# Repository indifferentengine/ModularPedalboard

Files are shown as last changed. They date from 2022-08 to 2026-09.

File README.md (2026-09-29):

# The Indifferent Engine Modular Pedalboard
A modular pedalboard system for guitars, bass and vocal effect rigs. 

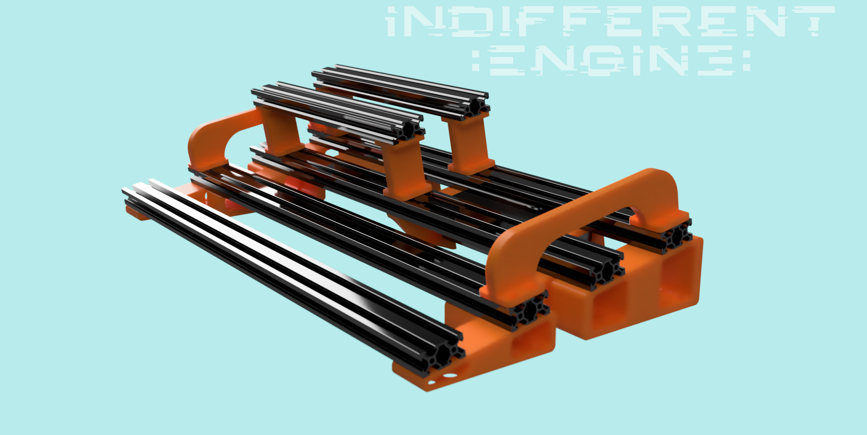
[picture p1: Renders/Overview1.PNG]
4x600mm board render


Constructed from 3D printed parts, off-the-shelf 2040 aluminium extrusion and velcro.

Simply print out the modular parts for the size and complexity of board you want and bolt them onto some aluminium extrusion.

# Designer App

We've launched a [designer app](https://www.indifferentengine.com/pedalboard) that you can use to mock up your pedalboard design. You can then either purchase the board as a self-assembly kit, or use the summary page to download the STLs for home printing.

# Where to find extrusions

Aluminium extrusions are standardised in width and profile, and are easy to find world-wide.

For this project, you need "2040 Aluminium Extrusion".

Extrusions can be found from many suppliers - often suppliers will cut the extrusions to length for you, simply google "2040 aluminium extrusion cut to length" to locate a supplier. Use the length of extrusion that matches the board width you want. For reference, Adam Paul's prototype board (shown in pictures at the bottom of this page) uses a set of four 600mm aluminium 2040 extrusion.

Here's the supplier we use (UK based):
[Ooznest](https://ooznest.co.uk/product/v-slot-linear-rail-20x40mm-cut-to-size/)

# Non-slip feet

The latest V2 release includes indentations for non-slip rubber feet. The feet we use are [3M™ Bumpon™ SJ 5007 Black Polyurethane Rubber Foot 10.2mm x 2.5mm](https://www.rapidonline.com/3m-bumpon-sj-5007-black-polyurethane-rubber-foot-10-2mm-x-2-5mm-single-49-4704)

# Different options

The components are designed to allow the user to build up a board of many different sizes and options.

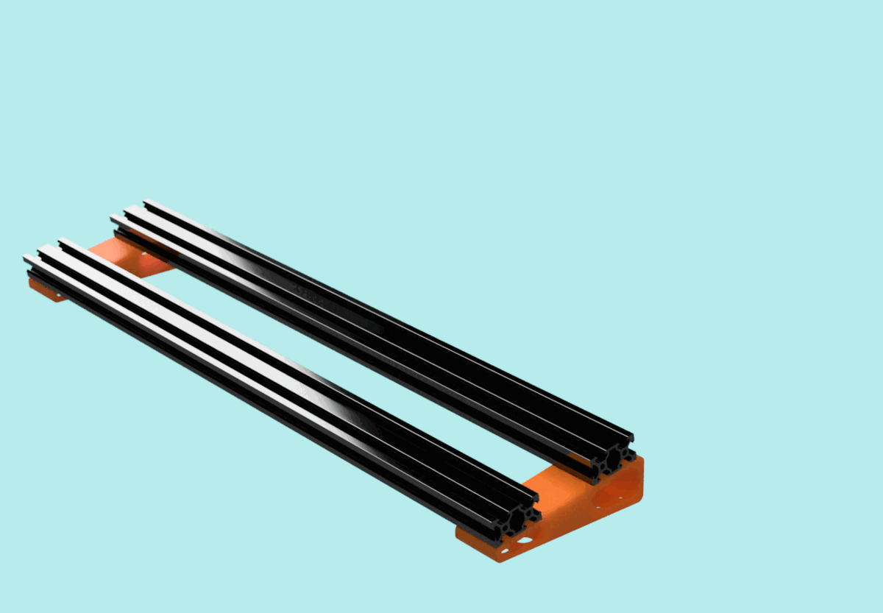
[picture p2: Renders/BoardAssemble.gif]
different board options gif


You can make boards of many sizes with this modular system. You can use 2, 3 or 4 rails and the length of the rails can be cut to whatever width of board you are after.

You could go as small as a 2 rail, 300mm wide board, like this:

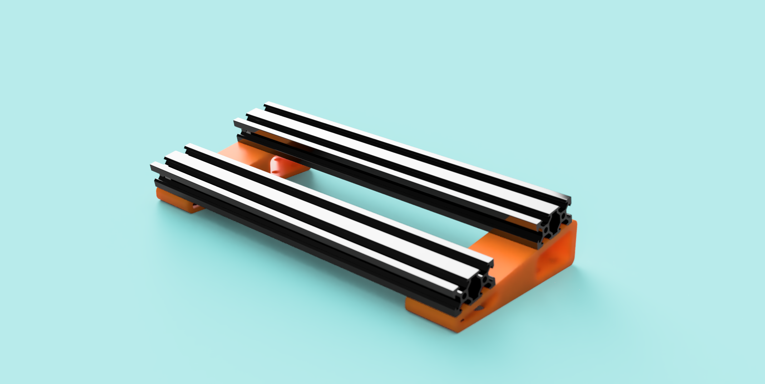
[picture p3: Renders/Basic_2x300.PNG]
basic 2x300mm board


Or as big as a 4 rail, 600mm wide board, like this:

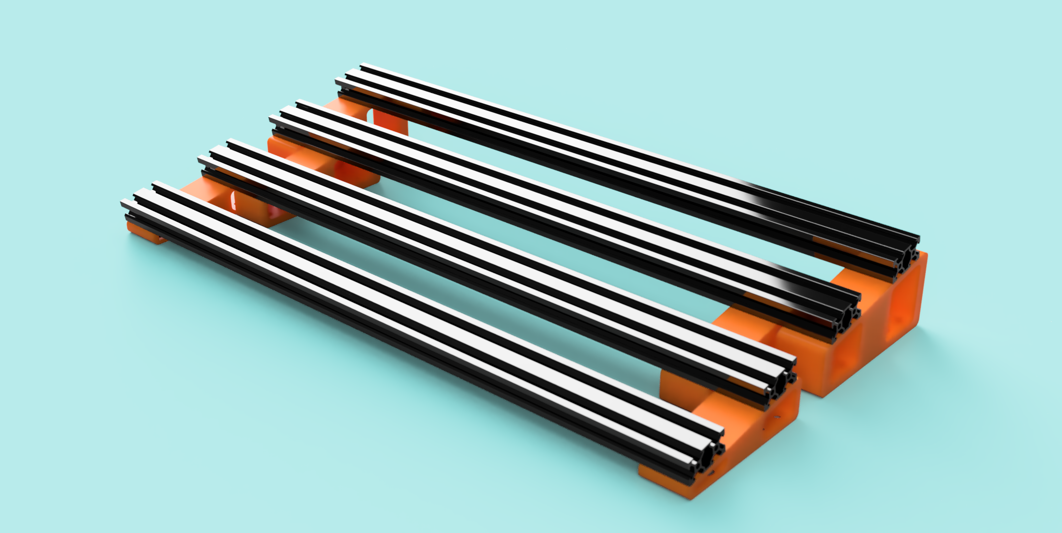
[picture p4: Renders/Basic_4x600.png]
basic 2x300mm board


You can even go wider than 600mm if you wanted to, especially if you add extra braces for the center of the board.

There are also a few extra options, I've included:
* A 4 in, 4 out patch bay that can be mounted either underneath or on-top of the board (on-top only for boards smaller than 4 rails). Designed to fit standard 1/4" open style jacks.
* A 2-piece handle that can be printed to go either end of the board (minimum 3 rail boards and up).
* A 2-piece tier support, which can be printed to allow the attachment of extra rails above the main board. These are designed to allow for boss-sized pedals to fit underneath the upper tier.
* An under-board powersupply mount for a T-Rex Chameleon (this is the power supply I have on hand). For 4-rail boards only.

The intention is to continue to support the project and further add to the range of modular parts to allow people to design a huge range of board setups.

# 3D Printing

We print these parts in PLA at 60% infill with 0.32 layer height. All parts print without supports.

# How To Build

Decide how many rails you want on your main board; 2, 3 or 4. You will need to print the following braces:

| Rails  | Braces required |
| ---| --- |
| 2 | 2x Brace1 |
| 3 | 2x Brace1, 2x Brace2 |
| 4 | 2x Brace1, 2x Brace2, 2xBrace3 |

Once completed, bolt your braces to the ends of the aluminium extrusion using 10mm M5 bolts and M5 T-slot nuts. Each brace requires 8 nuts and bolts. We recommend glueing some large rubber feet to the bottom of the braces to prevent the board from slipping around on stage.

If you want to add an upper tier you can use tier supports. Tier supports come in two pieces which sandwich together. So for a single upper rail, you will need 4x tier supports. Bolt the supports to both the upper and lower rails using 4x M5 bolts and T-slot nuts.

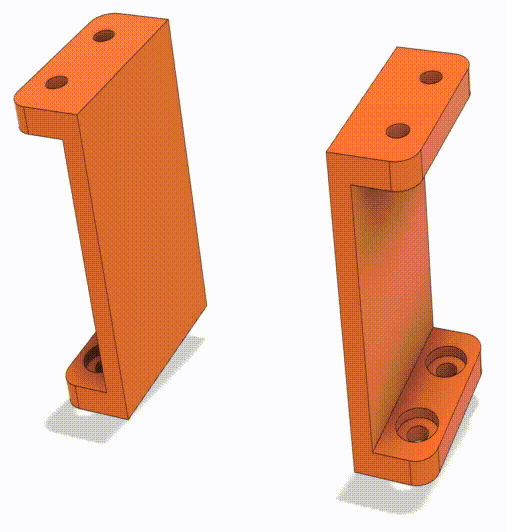
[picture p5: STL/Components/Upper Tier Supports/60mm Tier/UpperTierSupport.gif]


The patch bay requires 4x M5 bolts and T-slot nuts. The patchbay can be mounted to the top side of the board, or underneath the board in the case that you are building a 4-rail board. 

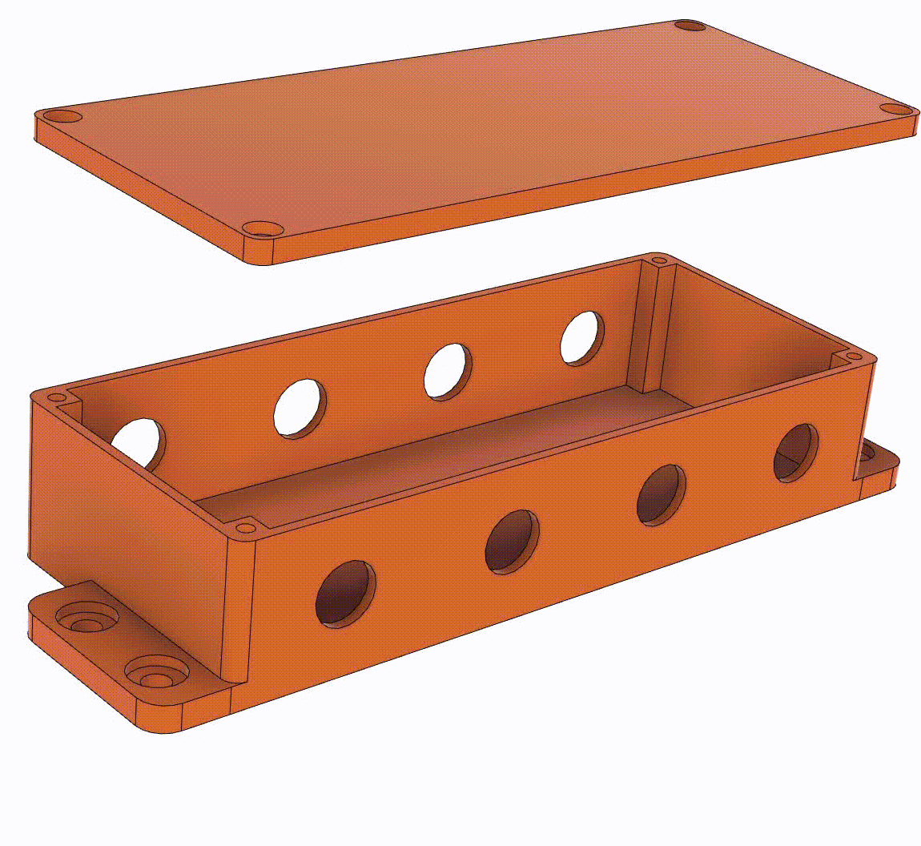
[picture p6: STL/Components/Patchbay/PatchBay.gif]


The powersupply mounting for T-rex Chameleon requires 8x M5 bolts and T-slot nuts, and only fits 4-rail boards. It must mount on the back 2 rails.

Handles are printed in 2 parts for each handle, in a similar way to the upper-tier support. Print both sides of the handle, then sandwich them together and bolt to the top side of the board. The handles require 8x M5 bolts and T-slot nuts. These handles can only be used on 3 and 4 rail boards.

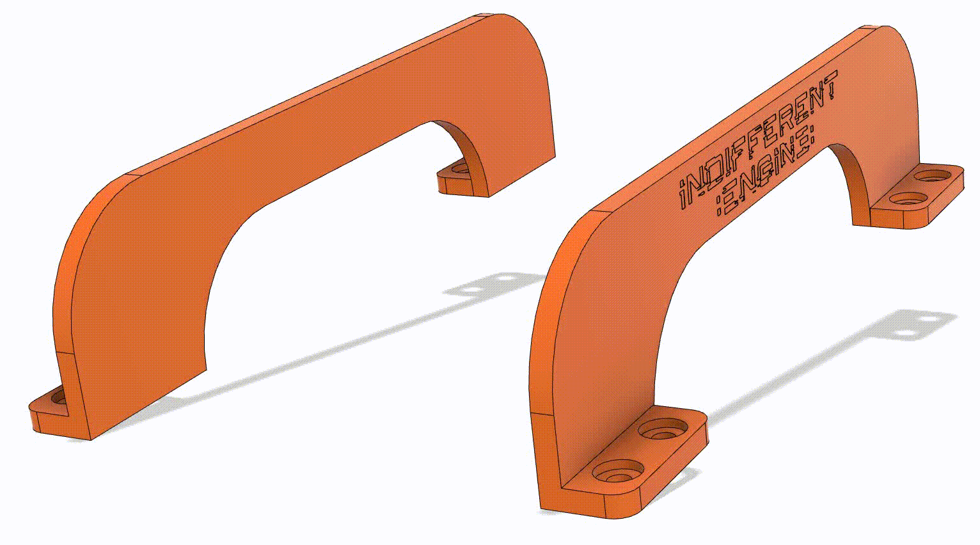
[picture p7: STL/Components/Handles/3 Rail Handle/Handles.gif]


Once the rails and other components are all mounted in place, simply cut some 40mm wide heavy-duty velcro carpet to length and stick it to the top of each rail. You're now ready to mount some pedals! Power and audio cabling can be run underneath the rails to keep it tidy, and you can use ziplocks to attach the cabling to the rails to keep it from trailing around under the board.

The following gif shows how a board with 4 rails, handles and an upper tier go together:



# Support the project

We may offer pedalboard kits in the future, keep an eye on our social stuff:
https://www.instagram.com/indifferentengine
https://www.facebook.com/indifferentengine

You can also help us out by checking out our merch store over here:
https://www.indifferentengine.com

If you want other ways to support us, considering buying one of our T-shirts, listening to our music or come to a show. Or just reach out for a chat.

# License

Licensed under GNU GPL v3. This means you are free to take this design and make any changes you like and then share those changes freely, so long as you make the source for your changes publicly available. This benefits everyone - because if you make some improvement, we can all benefit from it.

However, you cannot distribute compiled versions. In this context (a hardware device with CAD design), this effectively means you

a) cannot sell any physically manufactured item of any kind - either as parts or assembled.

b) cannot charge money for access to any source or CAD files that you choose to distribute

If you break these simple rules we will force you to be front row at one of our floor shows, where we can full-throat scream right in your sad little face.

If you would like a license to sell kits, contact us.

Everything is copyright (c) 2022 Indifferent Engine Ltd. Everything. OK? Indifferent Engine and the Indifferent Engine glitch logo are trademarks of Indifferent Engine Ltd.

# Photos
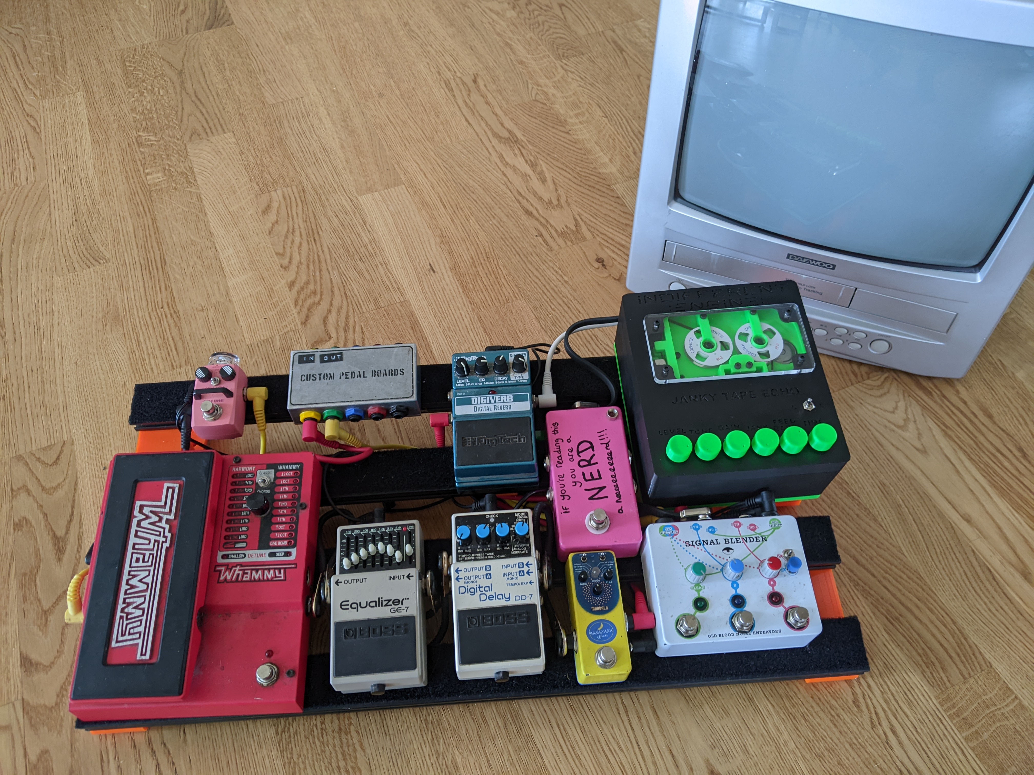
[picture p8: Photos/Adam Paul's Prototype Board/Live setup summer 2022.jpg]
Adams Board Top summer 2022

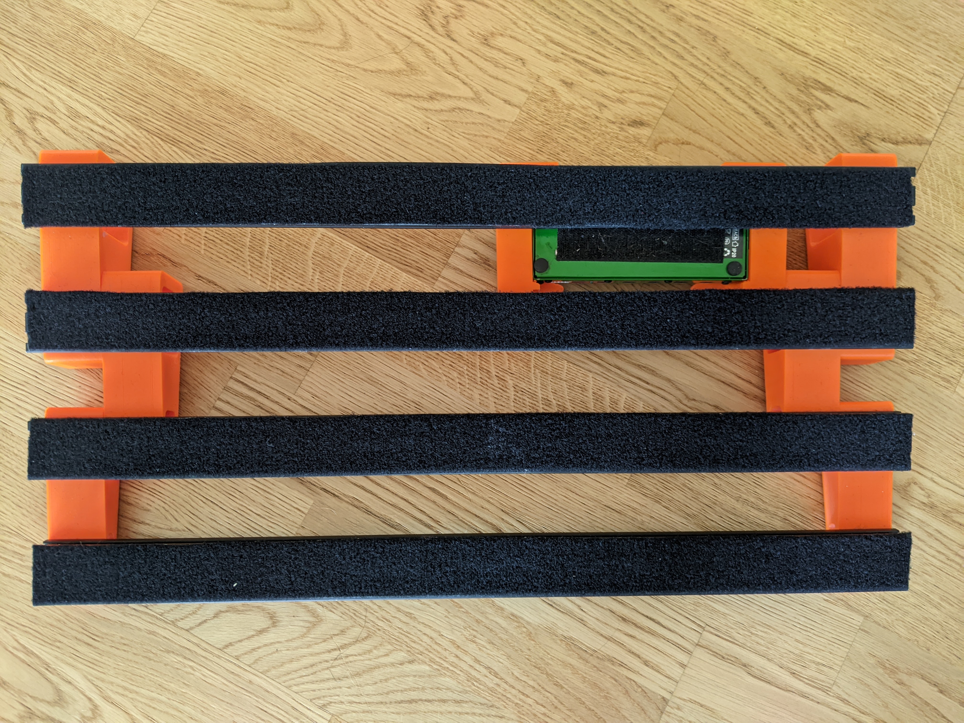
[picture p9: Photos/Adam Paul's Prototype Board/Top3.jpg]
Adams Board Top

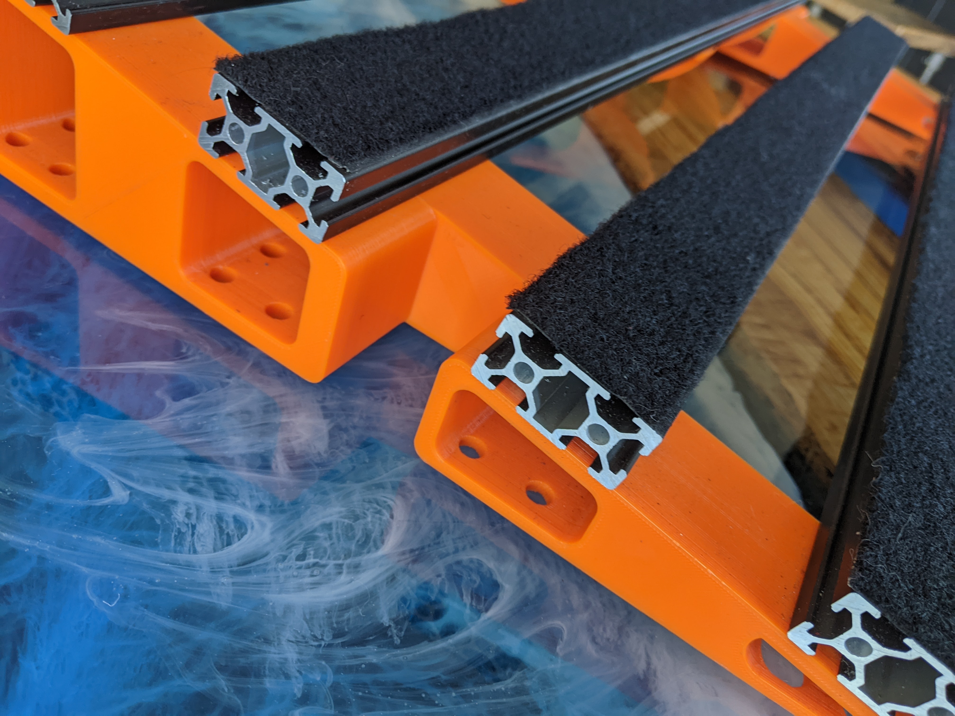
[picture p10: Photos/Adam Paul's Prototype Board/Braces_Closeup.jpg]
Adams Board Braces Closeup

Adams Board Rubber Feet
Adams Board TRex Chameleon mounting
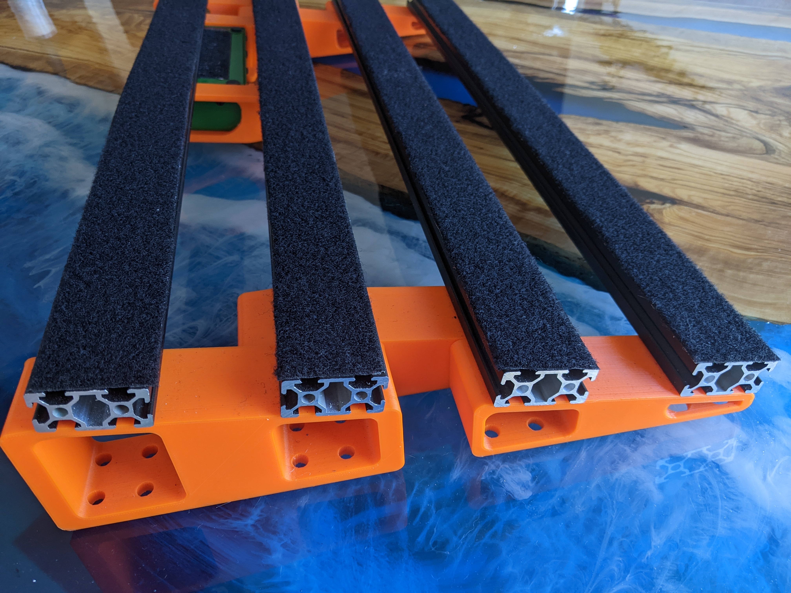
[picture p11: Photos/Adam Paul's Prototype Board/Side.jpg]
Adams Board Side


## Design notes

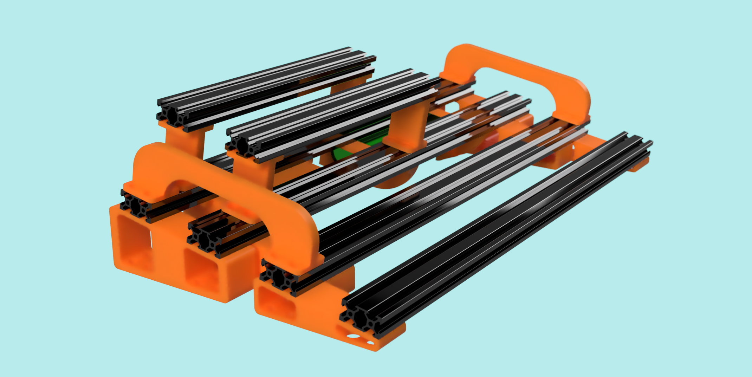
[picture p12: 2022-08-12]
Renders/Overview2.png

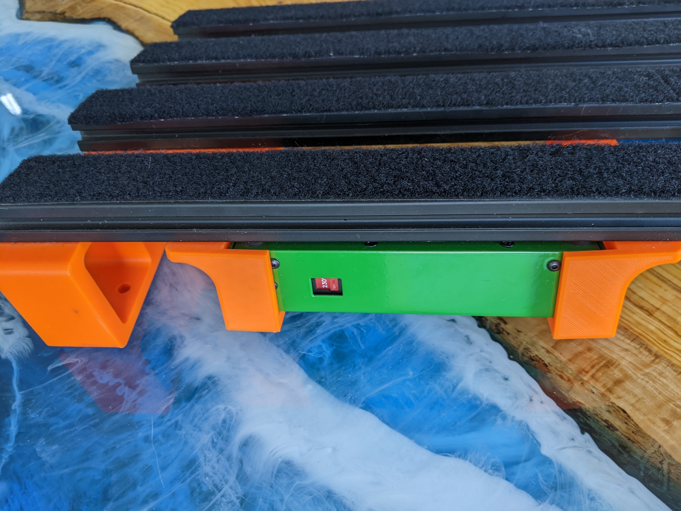
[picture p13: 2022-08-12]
Photos/Adam Paul's Prototype Board/TRexPowersupply_Back.jpg

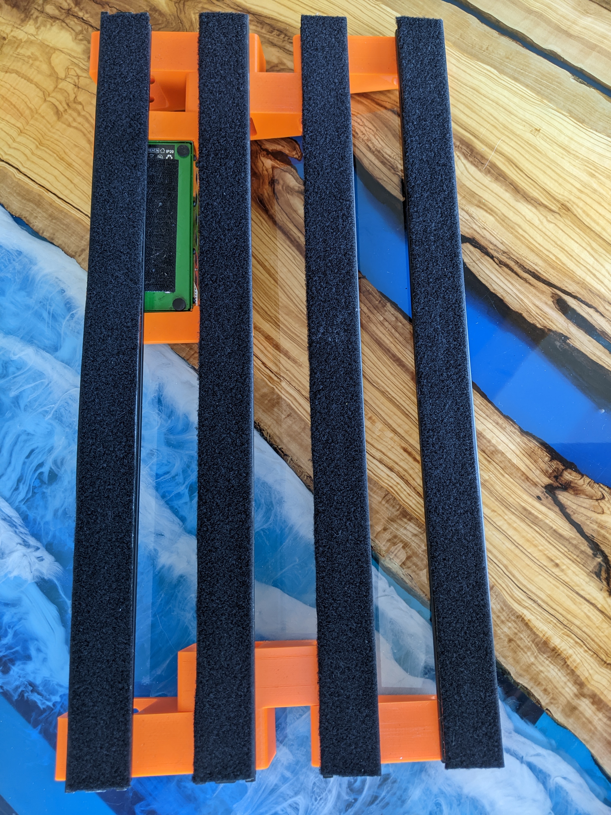
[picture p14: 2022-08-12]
Photos/Adam Paul's Prototype Board/Top2.jpg

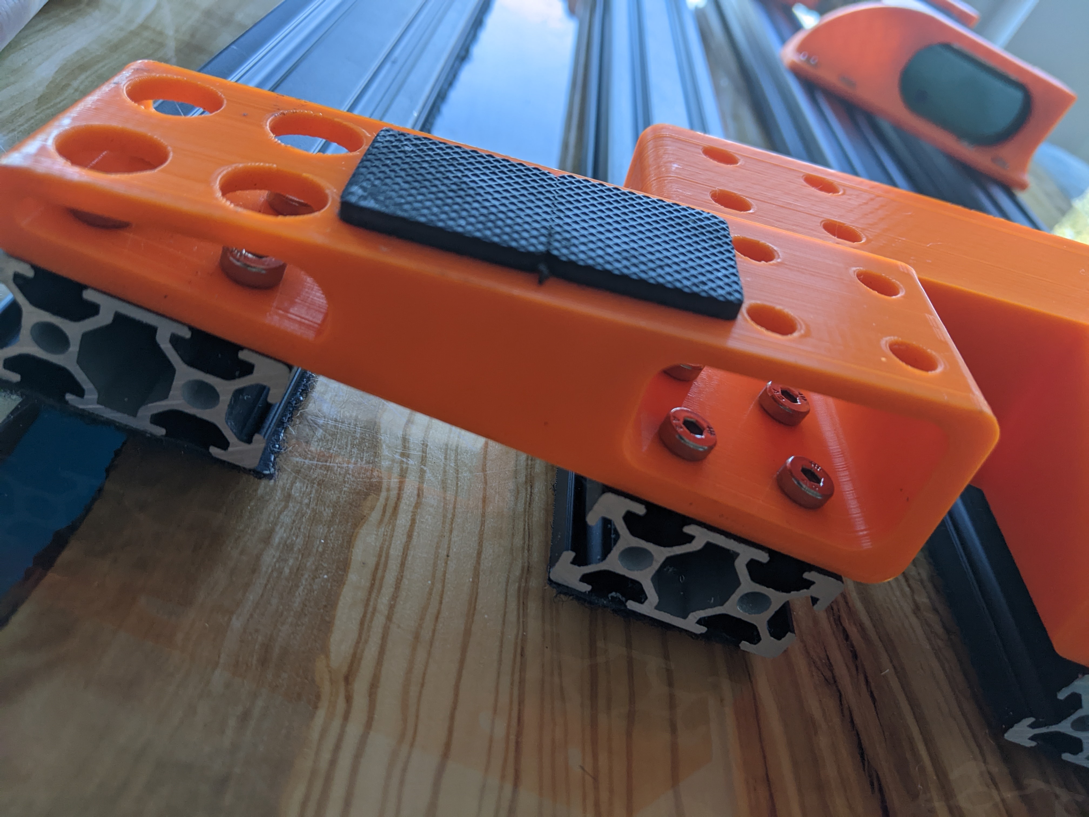
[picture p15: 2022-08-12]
Photos/Adam Paul's Prototype Board/RubberFeet1.jpg

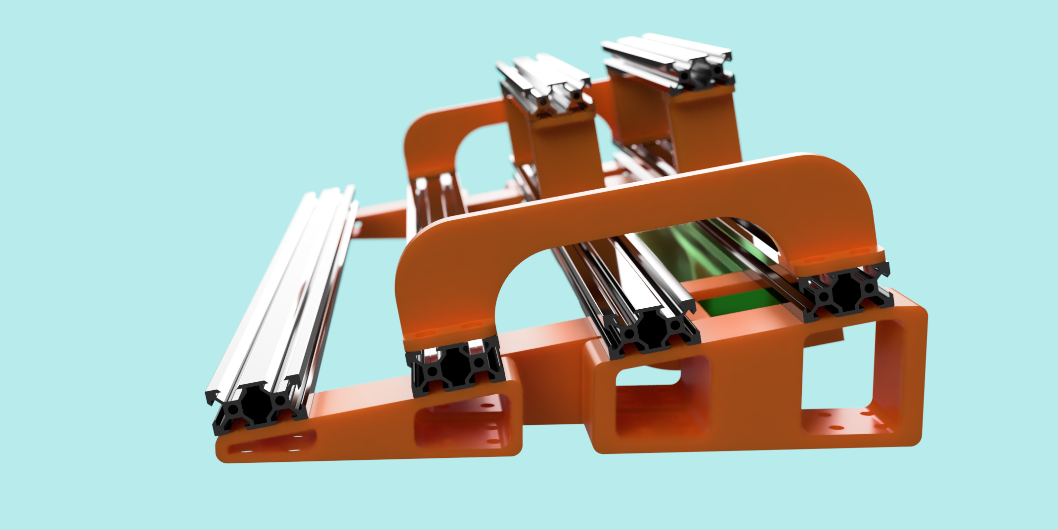
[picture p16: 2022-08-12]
Renders/side2.png

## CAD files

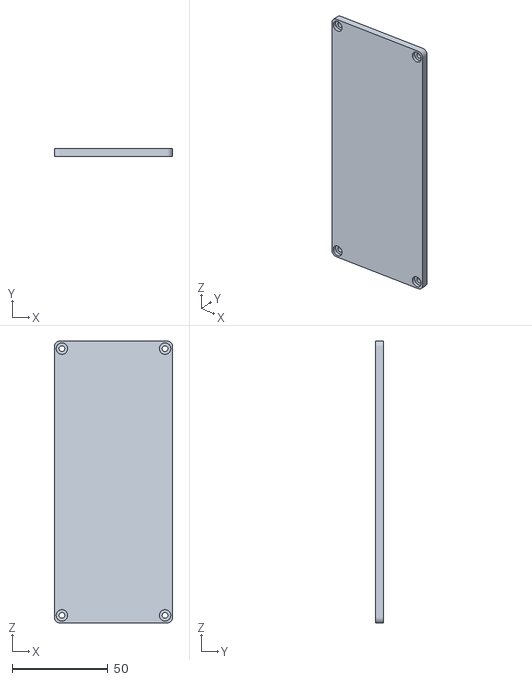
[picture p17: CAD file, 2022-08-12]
STL/Components/Patchbay/PatchBayLid.stl
62.0 x 4.00 x 147.6

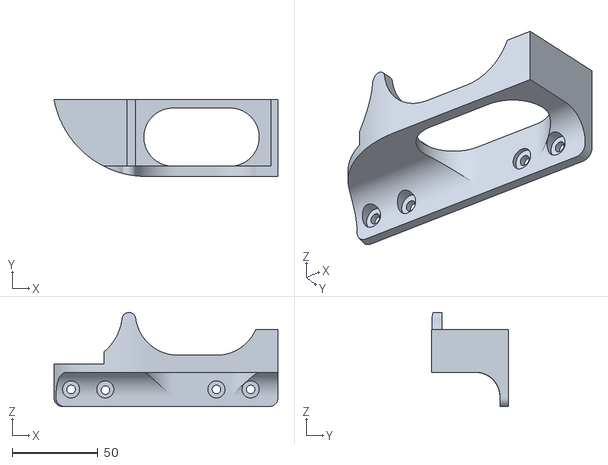
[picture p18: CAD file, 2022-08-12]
STL/Components/Power Supply Mounts/T-Rex Chameleon/PSUMount2.stl
131.0 x 45.0 x 55.0

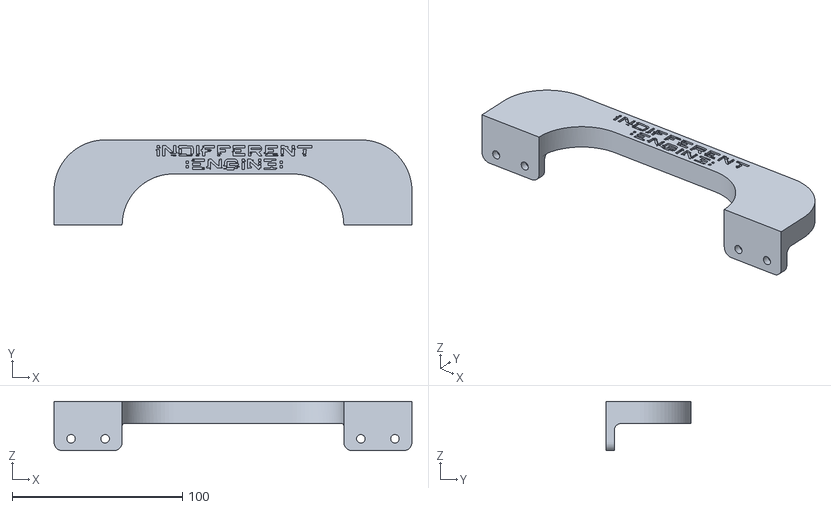
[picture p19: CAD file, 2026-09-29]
STL/part-handle1.stl
210.0 x 50.0 x 29.0

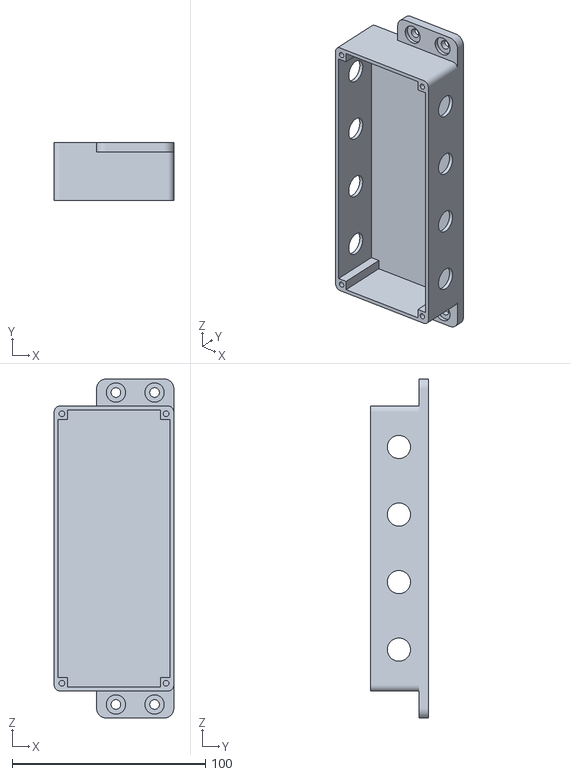
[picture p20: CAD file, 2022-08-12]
STL/Components/Patchbay/Patchbay.stl
62.0 x 30.0 x 175.6

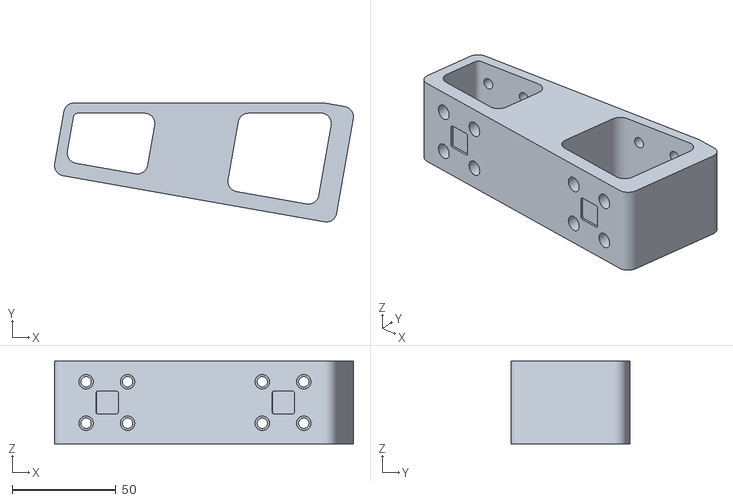
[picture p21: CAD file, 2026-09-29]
STL/part-brace-A2.stl
144.2 x 57.4 x 40.0

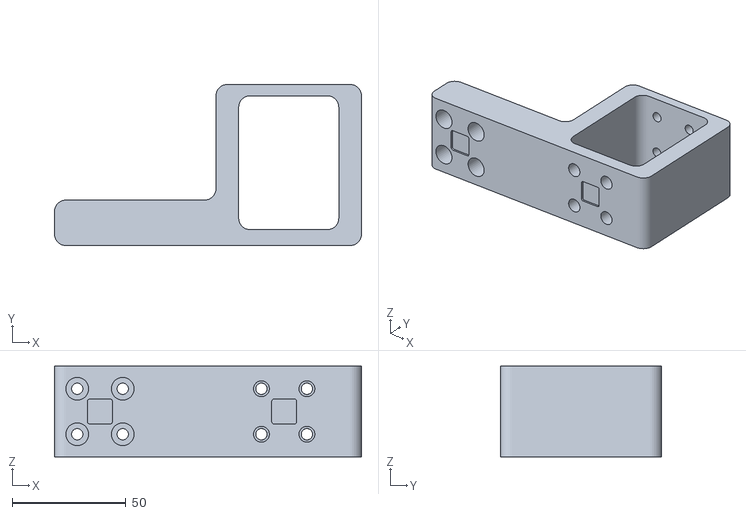
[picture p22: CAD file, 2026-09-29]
STL/part-brace-F1toF4.stl
135.0 x 70.9 x 40.0

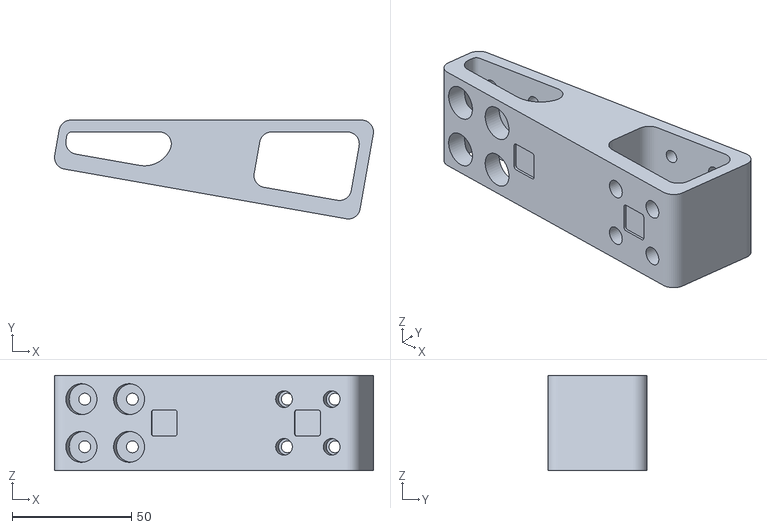
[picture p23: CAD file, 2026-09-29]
STL/part-brace-A1.stl
133.8 x 41.5 x 40.0

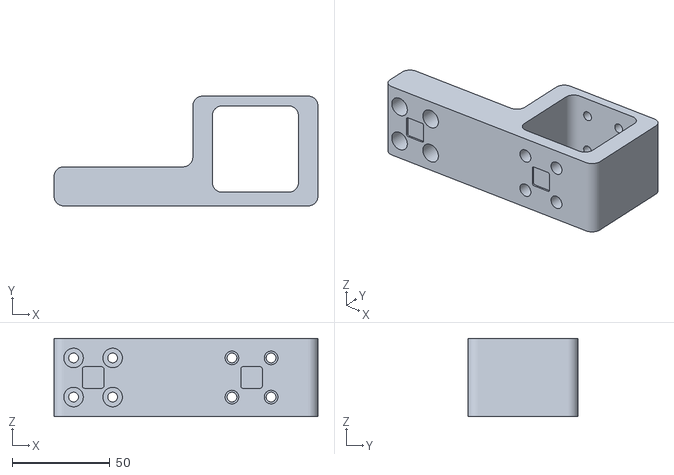
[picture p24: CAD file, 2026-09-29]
STL/part-brace-F1toF3.stl
135.0 x 56.2 x 40.0

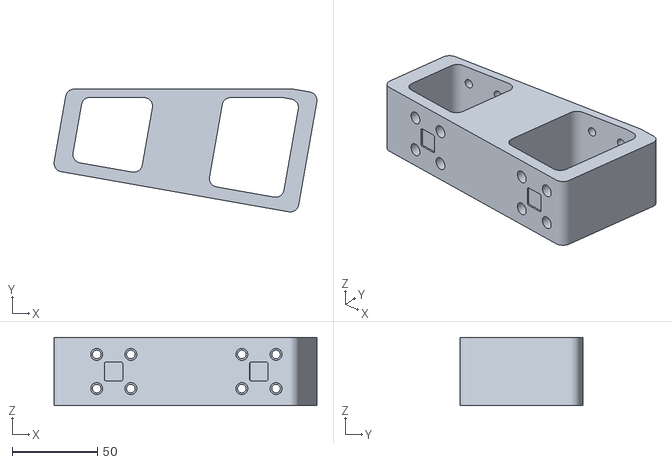
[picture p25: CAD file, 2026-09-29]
STL/part-brace-A3.stl
154.0 x 72.0 x 40.0

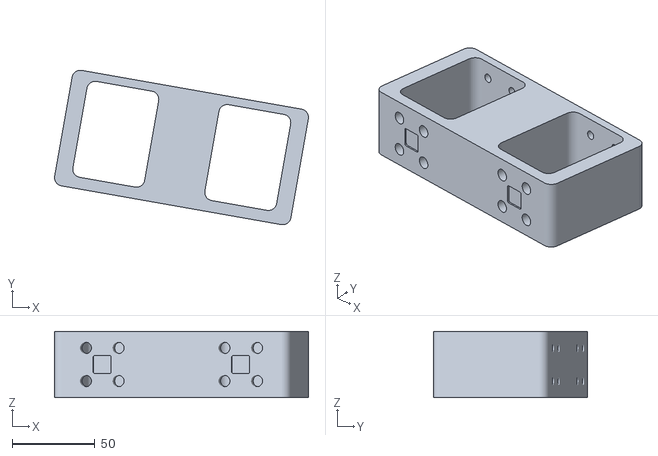
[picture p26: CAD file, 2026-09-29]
STL/part-brace-F4.stl
153.5 x 93.4 x 40.0

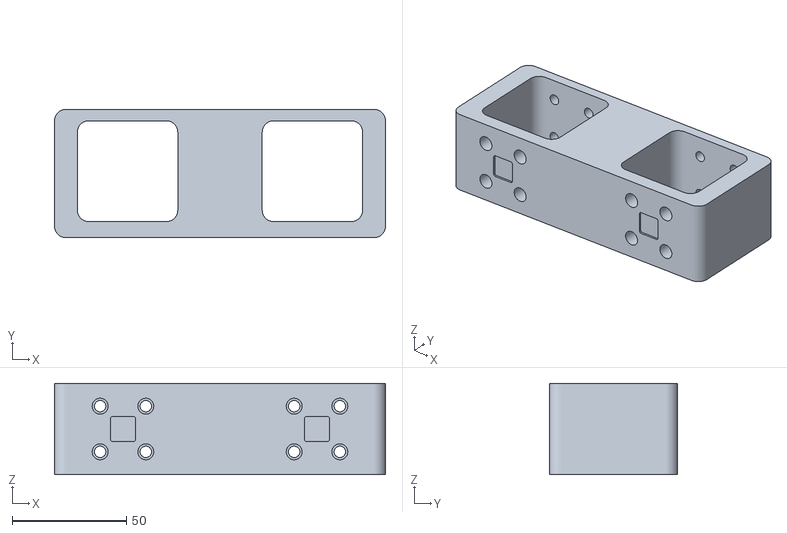
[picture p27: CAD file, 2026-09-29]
STL/part-brace-F3.stl
145.0 x 56.2 x 40.0

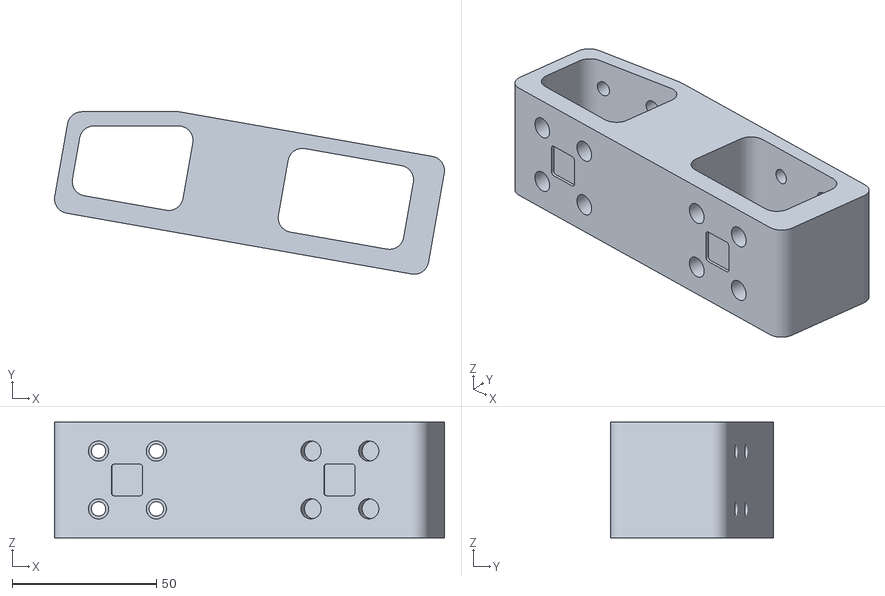
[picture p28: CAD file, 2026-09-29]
STL/part-brace-A2toF2.stl
135.0 x 56.3 x 40.0

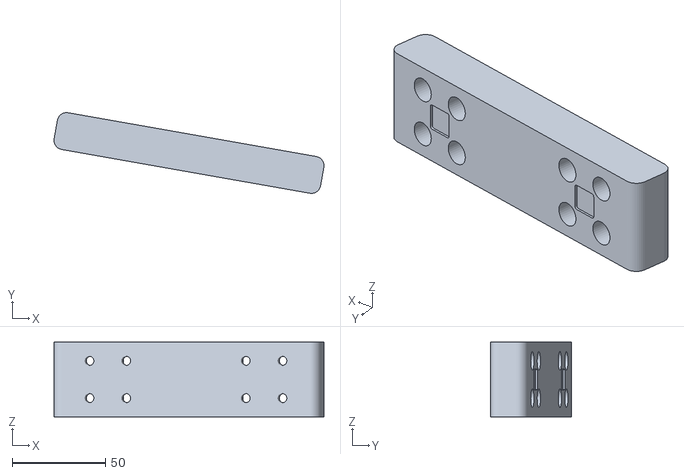
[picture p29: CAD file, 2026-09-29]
STL/part-brace-F1.stl
144.7 x 43.3 x 40.0

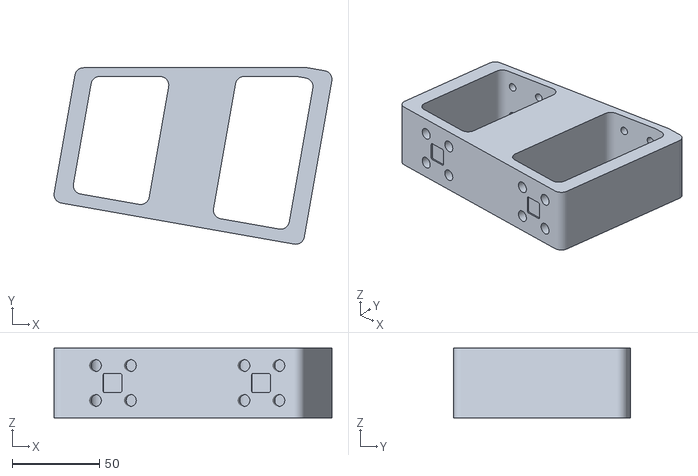
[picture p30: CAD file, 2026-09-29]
STL/part-brace-A5.stl
159.1 x 101.0 x 40.0

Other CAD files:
STL/Components/Power Supply Mounts/T-Rex Chameleon/PSUMount1.stl
STL/part-brace-F3toF4.stl
STL/part-brace-F2.stl
STL/part-brace-A4toF4.stl
STL/part-brace-A3toF3.stl
STL/part-brace-A4.stl
STL/part-brace-A5toF5.stl
STL/part-brace-F1toA1.stl
STL/part-brace-F1toF2.stl
STL/part-brace-F2toF3.stl
STL/part-brace-F2toF4.stl
STL/part-tiersupport1.stl

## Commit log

2022-08-12 First checkin of CAD and reference images.
2022-08-12 Added STLs for first pass components. Added photos of Adam Paul's prototype board.
    [Brace1.stl, Brace2.stl, Brace3.stl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]
2022-08-13 Moving STL files into meaningful folder structure
    [Handle1.stl, Handle2.stl, PSUMount1.stl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]
2022-08-13 Added simple assembly gifs for components
2022-08-13 Added some board assembly gifs showing how the board slots together
2022-08-13 Converted assembly mp4 to gif
2022-08-13 Added Adams board with pedals from 2022 run of shows
2022-08-17 Added 30 degree curved braces for making angled boards. Added braces 4 and 5 - now 6 rail boards are possible. Commiting latest CAD that includes new brace designs.
    [Brace1_Curved_30degrees.stl, Brace3_Curved_30degrees.stl, Brace4.stl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]
2023-09-04 Increased thickness of handle to make it more sturdy. Increaed thickness of tier supports. Added taller 80mm tier support. Added tilt-to-flat braces for brace 4 Added a flat brace for brace 5. -[todo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
    [Brace4_TiltToFlat.stl, Brace5_Flat.stl, Handle.stl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]
2026-09-29 V2 board production parts
    [Brace1.stl, Brace1_Curved_30degrees.stl, Brace2.stl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]
2026-09-29 Renaming all V2 STL files so that the names actually make some sort of sense
    [part-brace-A1.stl, part-brace-A2.stl, part-brace-A2toF2.stl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]
2026-09-29 Update bolt size and type for brace assembly
